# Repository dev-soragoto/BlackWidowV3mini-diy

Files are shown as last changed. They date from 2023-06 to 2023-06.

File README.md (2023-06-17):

# BlackWidowV3mini-diy

重新设计了BlackWidowV3mini的外壳，使用了gasket结构，外部无螺丝，窄边框。
重新绘制了矩阵pcb，单键开槽，热插拔。

## tips
1. 模型可直接用于3D打印，如要cnc的话需要自己更改外壳的热压螺母孔为m1螺纹孔，且重新考虑天线摆放位置。
2. 3d打印上盖可能因为有长条结构出现变形，建议多打印几个组装时选择相对完美的使用。

## 成品图

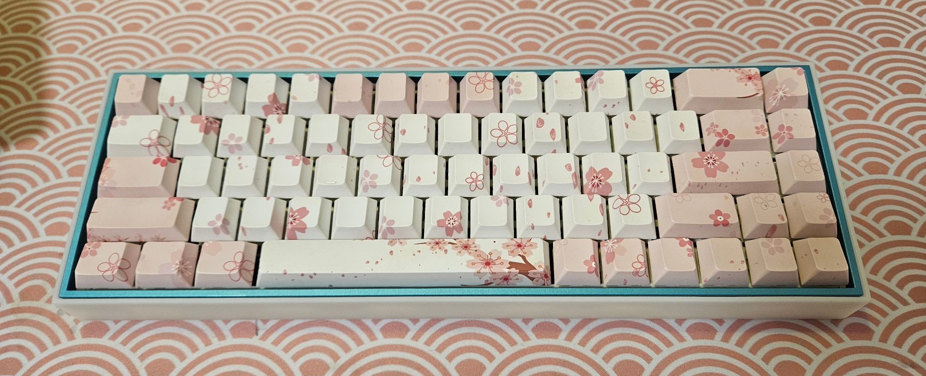
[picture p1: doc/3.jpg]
实物

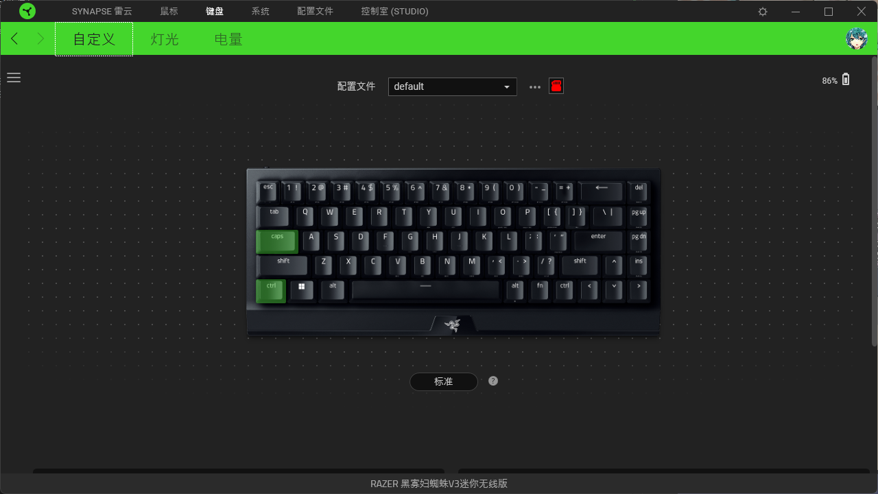
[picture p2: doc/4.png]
驱动


# 渲染图
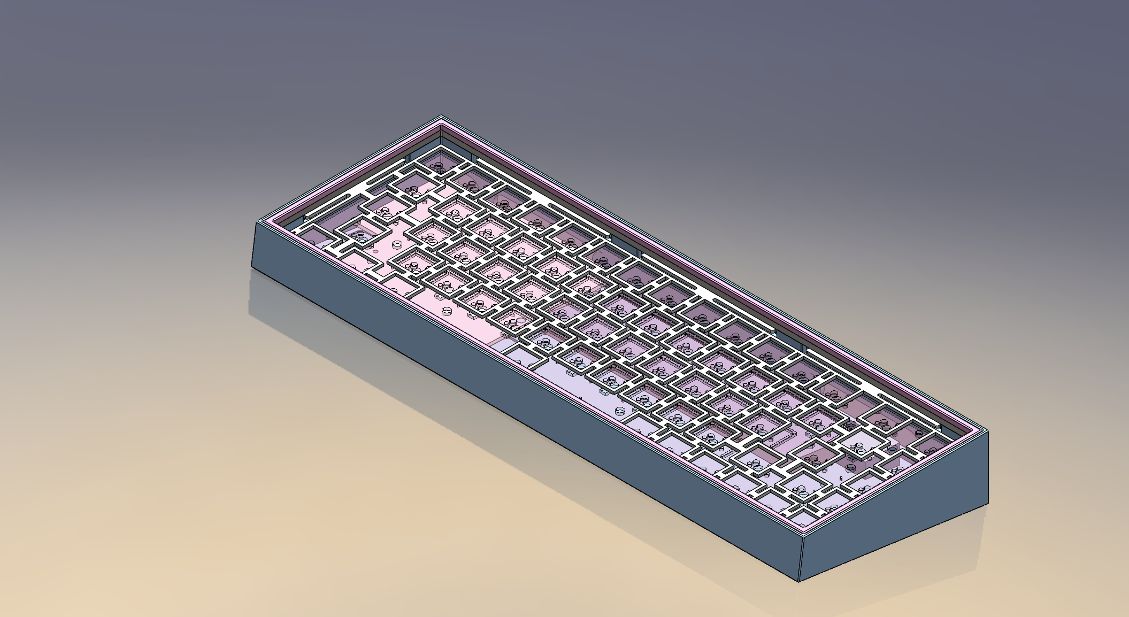
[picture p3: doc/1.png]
渲染

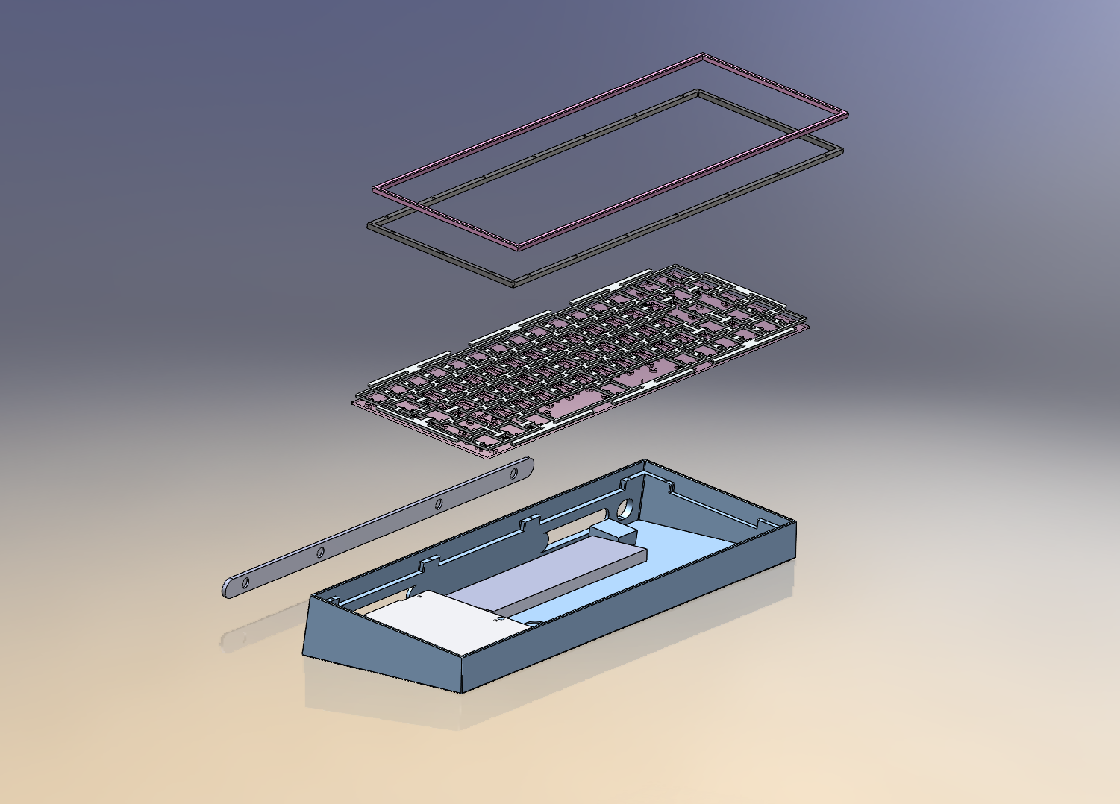
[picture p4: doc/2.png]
爆炸


## pcb
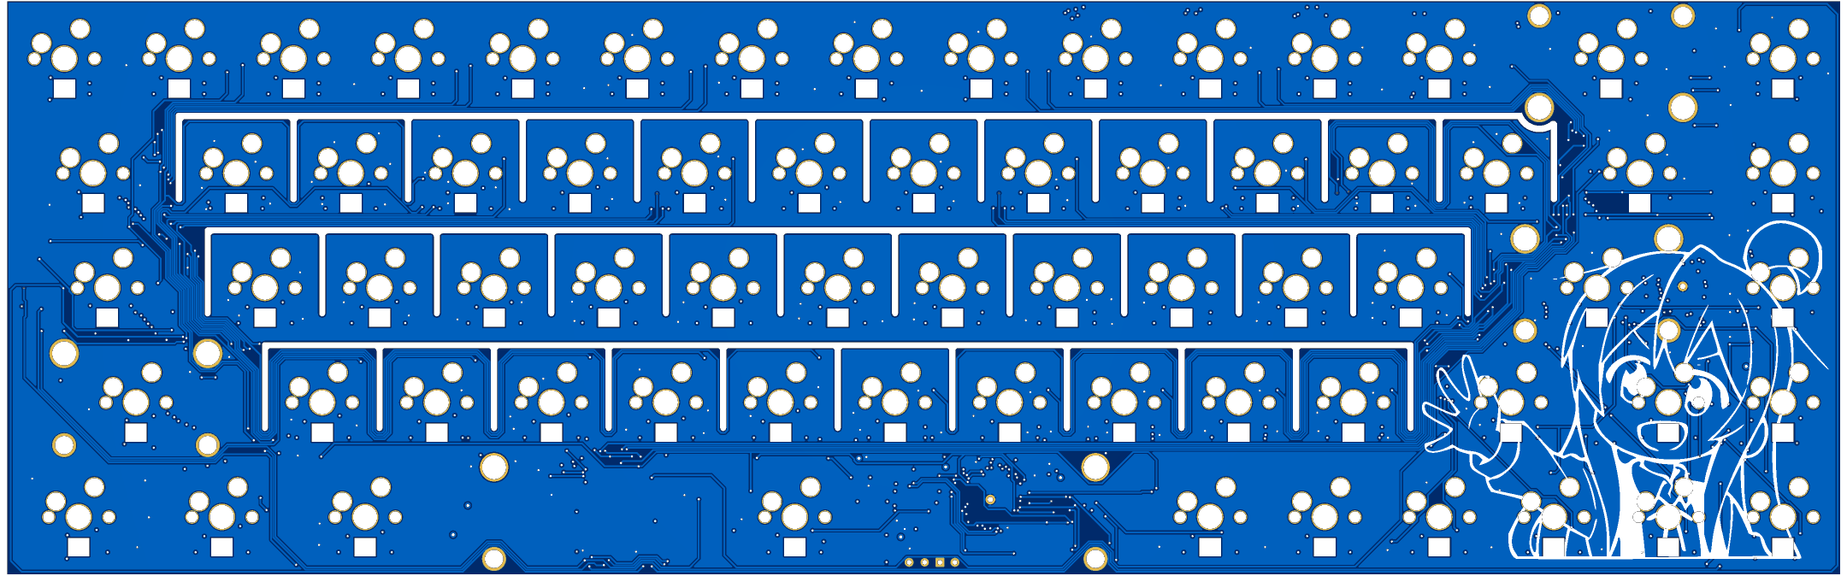
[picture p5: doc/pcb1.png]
pcb1

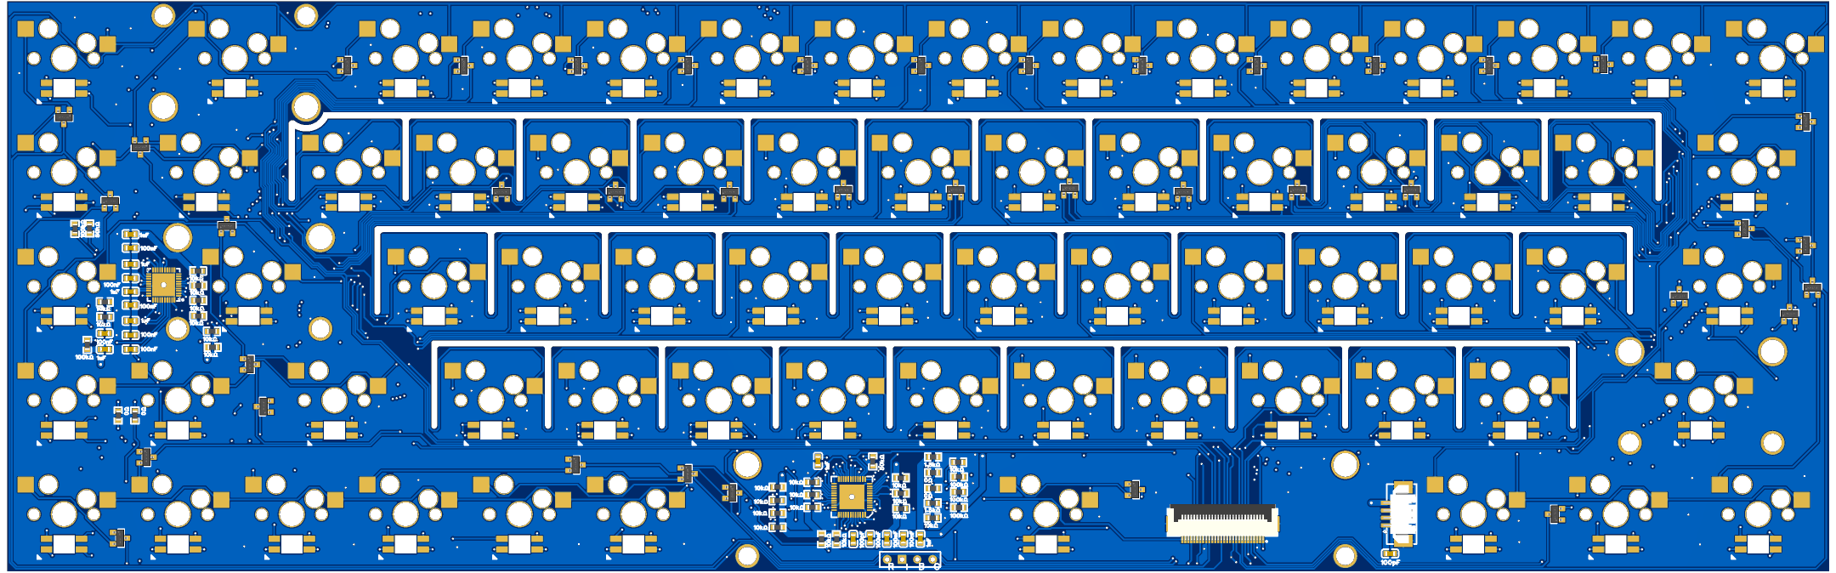
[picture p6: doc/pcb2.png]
pcb2


## bom
1. pcb的bom参考[`pcb-bom.csv`](doc/pcb-bom.csv)
2. 组装外壳你还需要准备

|物料|数量|备注|
|:-:|:-:|:-:|
|椭圆橡胶垫 18x6x2|4|用做脚垫|
|热压螺母 m1*1.5*1.8|12|安装在外壳与上盖的连接处|
|圆形强磁铁 Φ2*1|24|安装在两个上盖中|
|圆形强磁铁 Φ6*1|8|安装在外壳与名牌上|
|泡棉 20*3*2|32|定位板上|
|自攻螺丝 m2x5|4|固定主控小板|
|扁头螺丝 m1x5|12|连接外壳与上盖|
|razer-blackWidowV3mini|1|使用原键盘的主控小板,接收器等部件|

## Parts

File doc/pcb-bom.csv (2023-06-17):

Quantity | Footprint | Value | Device
68 | 热插拔轴座 |  | 热插拔轴座
68 | 3528/6028 |  | 缺口蓝色反贴rgb
1 | VQFN-48_L6.0-W6.0-P0.50-BL-EP |  | IS31FL3733-QFLS4-TR(建议搬板)
1 | UQFN-40_L5.0-W5.0-P0.40-BL-EP3.7 |  | IS31FL3737-QFLS4-TR(建议搬板)
1 | 雷蛇LOGO插件灯 |  | 雷蛇LOGO插件灯
9 | C0603 | 100nF | CL10B104KB8NNNC
7 | C0603 | 1uF | CL10A105KB8NNNC
1 | CONN-SMD_4P-P1.25_HDGC-HDGC1251WR-S-4P |  | HDGC1251WR-S-4P
40 | SOT-23_L2.9-W1.3-P1.90-LS2.4-BR |  | BAW56_C2136
5 | R0603 | 100kΩ | 0603WAF1003T5E
2 | R0603 | 50kΩ | AR03BTC5002A
4 | R0603 | 0Ω | 0603WAF0000T5E
22 | R0603 | 10kΩ | 0603WAF1002T5E
2 | R0603 | 1.5kΩ | 0603WAF1501T5E
2 | C0603 | 100pF | CC0603JRNPO9BN101
1 | FPC-SMD_28P-P0.50_FPC-05F-28PH20 |  | FPC-05F-28PH20

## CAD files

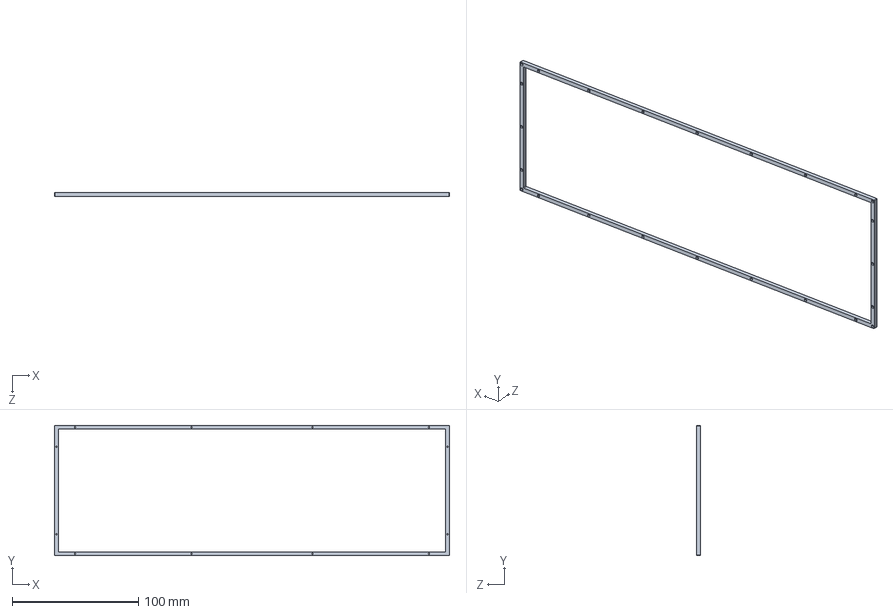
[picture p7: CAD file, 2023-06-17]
step/上盖1.STEP
312.6 x 103.2 x 3.00 mm

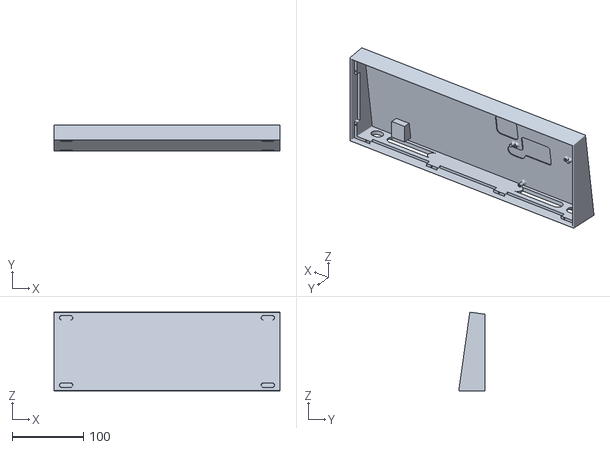
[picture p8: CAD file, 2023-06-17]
stl/keyboard - 外壳-1.STL
316.6 x 37.0 x 110.2

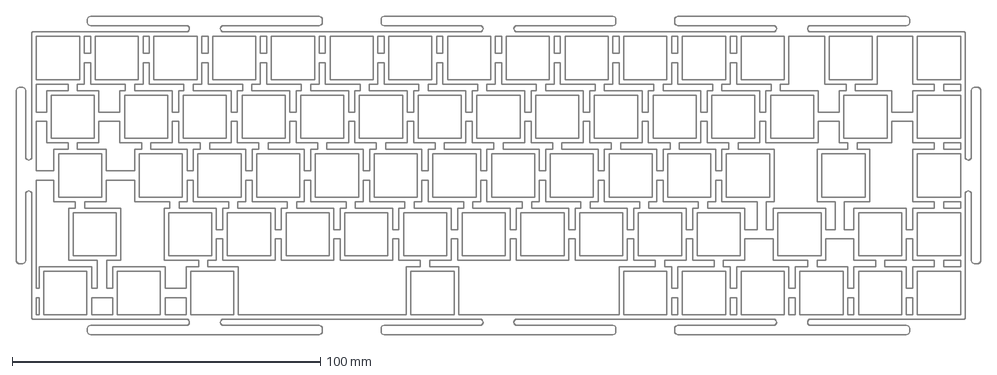
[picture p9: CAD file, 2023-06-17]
step/定位板.dxf
312.8 x 103.3 mm

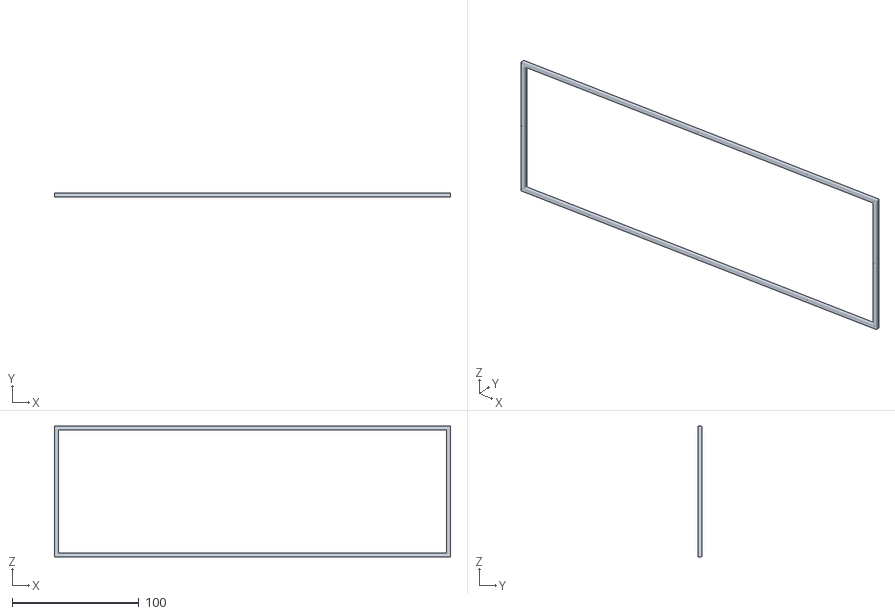
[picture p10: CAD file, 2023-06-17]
stl/keyboard - 上盖2-1.STL
312.6 x 3.00 x 103.2

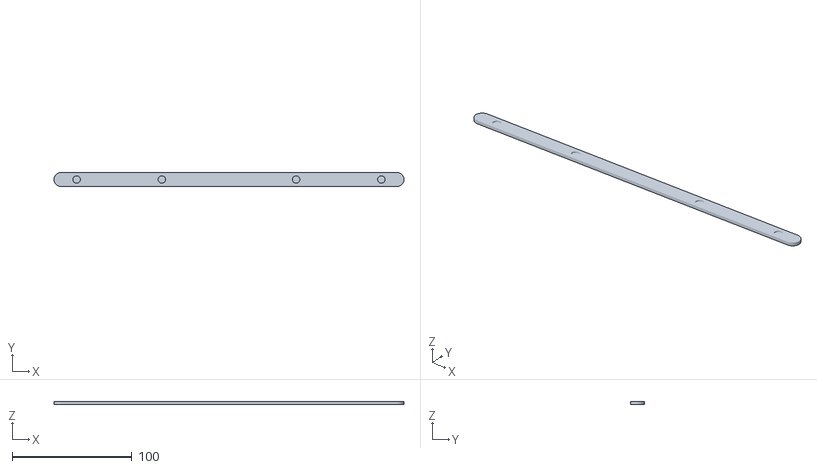
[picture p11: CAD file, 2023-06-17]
stl/keyboard - 名牌-1.STL
291.8 x 11.8 x 2.90

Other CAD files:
stl/keyboard - 上盖1-1.STL
step/外壳.STEP
step/上盖2.STEP
step/名牌.STEP
